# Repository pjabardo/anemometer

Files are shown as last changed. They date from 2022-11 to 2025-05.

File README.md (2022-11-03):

# envconds
Temperature, Pressure and Humidity measurement board and software

The objective of this project is to develop a board that reads environmental conditions including
 * Temperature using DS18B20 sensor
 * Pressure using the BMP280 sensor
 * Humidity using the DHT22 sensor

In the future, more sensors could be added.

The board uses a ESP32 microcontroller, in particular the Devkit v1 board with 30 pins. Embeded programming is done using arduino framework.

The folder `kicad` contains the schematics of the board.

For now a simple communication protocol over the serial line is used. In the future MQTT should be used.

To read a value, user should send the command `*XY` where `X` refers to the sensor and `Y` the variable being read. The following variables can be read:

 * `HH` - Humidity from the DHT22
 * `HT` - Temperature from the DHT22
 * `PP` - Atmospheric pressure from the BMP280
 * `PT` - Temperature from the BMP280
 * `Tx' - where x is the temperature sensor.

 To read the atmospheric pressure, the command `*PP` should be sent to the microcontroller. The response is sent as a line of text containing the value as an ASCII string.

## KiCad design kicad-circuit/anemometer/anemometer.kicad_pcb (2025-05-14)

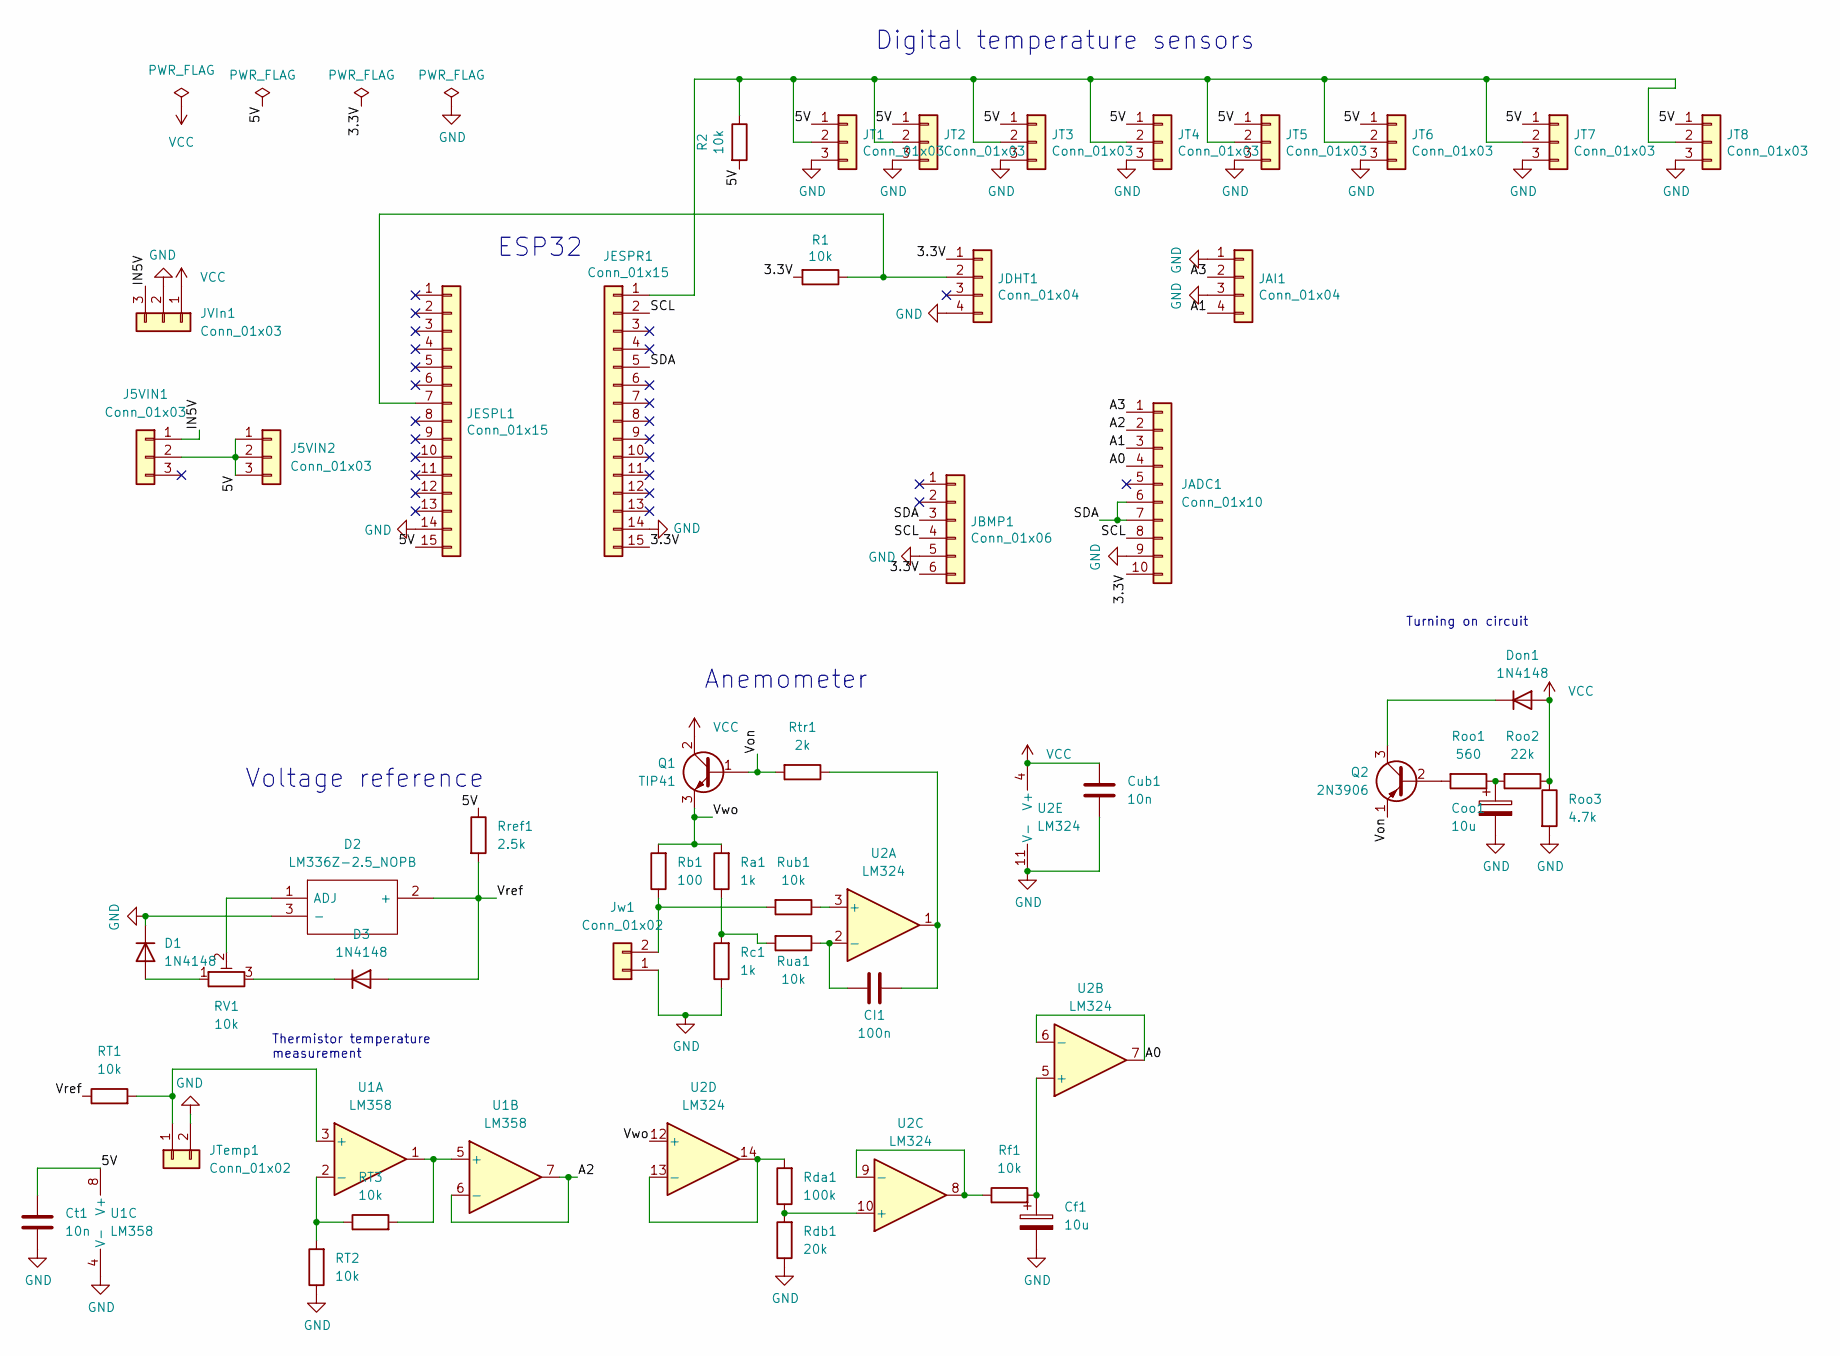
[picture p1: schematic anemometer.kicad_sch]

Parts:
CI1: 100n; C_Rect_L7.2mm_W3.5mm_P5.00mm_FKS2_FKP2_MKS2_MKP2
Cf1: 10u; CP_Radial_D5.0mm_P2.50mm
Coo1: 10u; CP_Radial_D5.0mm_P2.50mm
Ct1: 10n; C_Disc_D5.0mm_W2.5mm_P2.50mm
Cub1: 10n; C_Disc_D5.0mm_W2.5mm_P2.50mm
D1, D3: 1N4148; D_DO-35_SOD27_P7.62mm_Horizontal
D2: LM336Z-2.5_NOPB; TO-92_Inline_Wide; Manufacturer_Part_Number LM336Z-2.5/NOPB; Mouser Part Number 926-LM336Z-2.5/NOPB
Don1: 1N4148; D_DO-35_SOD27_P7.62mm_Horizontal
J5VIN1, J5VIN2: Conn_01x03; PinSocket_1x03_P2.54mm_Vertical
JADC1: Conn_01x10; PinSocket_1x10_P2.54mm_Vertical
JAI1: Conn_01x04; TerminalBlock_bornier-4_P5.08mm
JBMP1: Conn_01x06; PinSocket_1x06_P2.54mm_Vertical
JDHT1: Conn_01x04; PinSocket_1x04_P2.54mm_Vertical
JESPL1: Conn_01x15; PinSocket_1x15_P2.54mm_Vertical
JESPR1: Conn_01x15; PinSocket_1x15_P2.54mm_Vertical
JT1, JT2, JT3, JT4, JT5, JT6, JT7, JT8: Conn_01x03; PinHeader_1x03_P2.54mm_Vertical
JTemp1: Conn_01x02; TerminalBlock_bornier-2_P5.08mm
JVIn1: Conn_01x03; TerminalBlock_bornier-3_P5.08mm
Jw1: Conn_01x02; TerminalBlock_bornier-2_P5.08mm
Q1: TIP41; TO-220-3_Horizontal_TabUp
Q2: 2N3906; TO-92_Inline_Wide
R1, R2: 10k; R_Axial_DIN0207_L6.3mm_D2.5mm_P10.16mm_Horizontal
RT1, RT2, RT3: 10k; R_Axial_DIN0207_L6.3mm_D2.5mm_P10.16mm_Horizontal
RV1: 10k; Potentiometer_Bourns_3296W_Vertical
Ra1: 1k; R_Axial_DIN0207_L6.3mm_D2.5mm_P10.16mm_Horizontal
Rb1: 100; R_Axial_DIN0414_L11.9mm_D4.5mm_P15.24mm_Horizontal
Rc1: 1k; R_Axial_DIN0207_L6.3mm_D2.5mm_P10.16mm_Horizontal
Rda1: 100k; R_Axial_DIN0207_L6.3mm_D2.5mm_P10.16mm_Horizontal
Rdb1: 20k; R_Axial_DIN0207_L6.3mm_D2.5mm_P10.16mm_Horizontal
Rf1: 10k; R_Axial_DIN0207_L6.3mm_D2.5mm_P10.16mm_Horizontal
Roo1: 560; R_Axial_DIN0207_L6.3mm_D2.5mm_P10.16mm_Horizontal
Roo2: 22k; R_Axial_DIN0207_L6.3mm_D2.5mm_P10.16mm_Horizontal
Roo3: 4.7k; R_Axial_DIN0207_L6.3mm_D2.5mm_P10.16mm_Horizontal
Rref1: 2.5k; R_Axial_DIN0207_L6.3mm_D2.5mm_P10.16mm_Horizontal
Rtr1: 2k; R_Axial_DIN0207_L6.3mm_D2.5mm_P10.16mm_Horizontal
Rua1: 10k; R_Axial_DIN0207_L6.3mm_D2.5mm_P10.16mm_Horizontal
Rub1: 10k; R_Axial_DIN0207_L6.3mm_D2.5mm_P10.16mm_Horizontal
U1: LM358; DIP-8_W7.62mm_LongPads
U2: LM324; DIP-14_W7.62mm_Socket_LongPads

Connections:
/3.3V: JADC1.10, JBMP1.6, JDHT1.1, JESPR1.15, R1.2
/5V: Ct1.1, J5VIN1.2, J5VIN2.1, J5VIN2.2, J5VIN2.3, JESPL1.15, JT1.1, JT2.1, JT3.1, JT4.1, JT5.1, JT6.1, JT7.1, JT8.1, R2.2, Rref1.1, U1.8 (V+)
/A0: JADC1.4, U2.6 (-), U2.7
/A1: JADC1.3, JAI1.4
/A2: JADC1.2, U1.6 (-), U1.7
/A3: JADC1.1, JAI1.2
/IN5V: J5VIN1.1, JVIn1.3
/SCL: JADC1.8, JBMP1.4, JESPR1.2
/SDA: JADC1.6, JADC1.7, JBMP1.3, JESPR1.5
/Von: Q1.1 (B), Q2.1 (E), Rtr1.2
/Vref: D2.2 (+), D3.2 (A), RT1.1, Rref1.2
/Vwo: Q1.3 (E), Ra1.2, Rb1.2, U2.12 (+)
GND: Cf1.2, Coo1.2, Ct1.2, Cub1.2, D1.1 (K), D2.3 (-), JADC1.9, JAI1.1, JAI1.3, JBMP1.5, JDHT1.4, JESPL1.14, JESPR1.14, JT1.3, JT2.3, JT3.3, JT4.3, JT5.3, JT6.3, JT7.3, JT8.3, JTemp1.2, JVIn1.2, Jw1.1, RT2.1, Rc1.1, Rdb1.1, Roo3.2, U1.4 (V-), U2.11 (V-)
unnamed: CI1.1, Rua1.1, U2.2 (-)
unnamed: CI1.2, Rtr1.1, U2.1
unnamed: Cf1.1, Rf1.2, U2.5 (+)
unnamed: Coo1.1, Roo1.1, Roo2.2
unnamed: D1.2 (A), RV1.1
unnamed: D2.1 (ADJ), RV1.2
unnamed: D3.1 (K), RV1.3
unnamed: Don1.1 (K), Q2.3 (C)
unnamed: JDHT1.2, JESPL1.7, R1.1
unnamed: JESPR1.1, JT1.2, JT2.2, JT3.2, JT4.2, JT5.2, JT6.2, JT7.2, JT8.2, R2.1
unnamed: JTemp1.1, RT1.2, U1.3 (+)
unnamed: Jw1.2, Rb1.1, Rub1.2
unnamed: Q2.2 (B), Roo1.2
unnamed: RT2.2, RT3.1, U1.2 (-)
unnamed: RT3.2, U1.1, U1.5 (+)
unnamed: Ra1.1, Rc1.2, Rua1.2
unnamed: Rda1.1, Rdb1.2, U2.10 (+)
unnamed: Rda1.2, U2.13 (-), U2.14
unnamed: Rf1.1, U2.8, U2.9 (-)
unnamed: Rub1.1, U2.3 (+)
VCC: Cub1.1, Don1.2 (A), JVIn1.1, Q1.2 (C), Roo2.1, Roo3.1, U2.4 (V+)

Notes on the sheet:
ESP32
Thermistor temperature measurement
Digital temperature sensors
Turning on circuit
Anemometer
Voltage reference

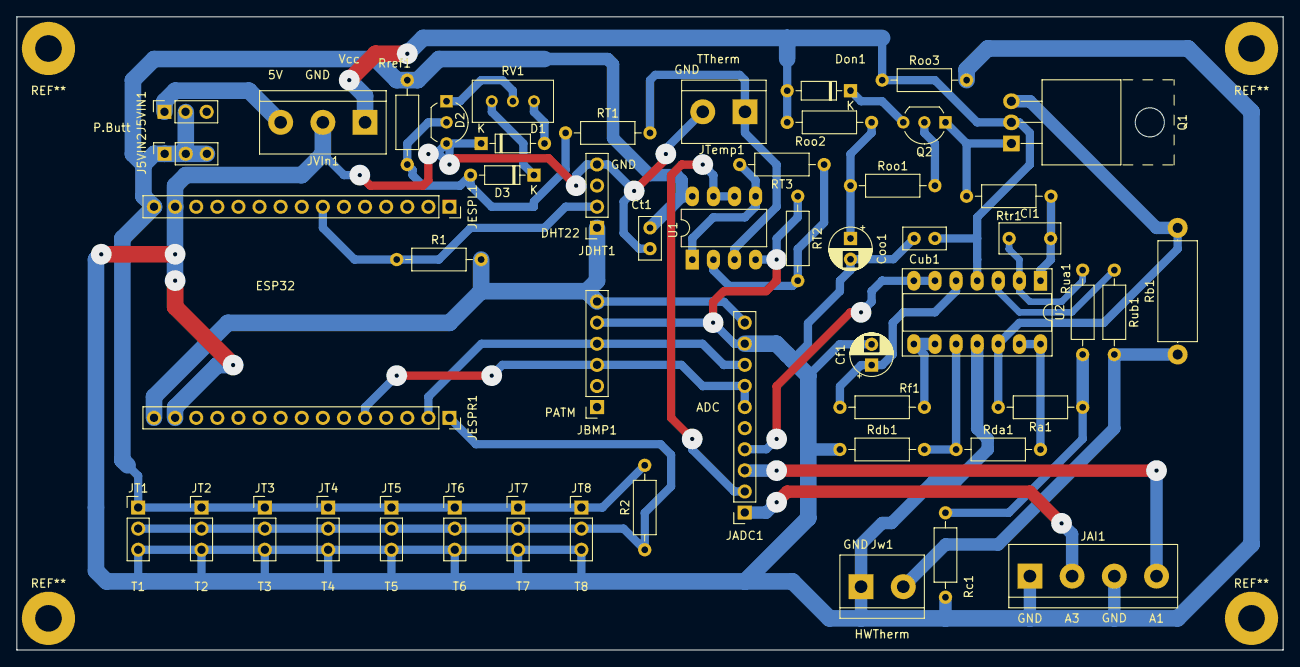
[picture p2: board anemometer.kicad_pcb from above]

Board: 2 copper layers, 152.4 x 76.2 mm, 51 parts (0 on the bottom side), 34 nets.

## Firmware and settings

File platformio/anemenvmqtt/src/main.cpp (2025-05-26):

#include<WiFi.h>

#include "mqtt_anem.h"


Anemometer anem;

const char *ssid = "rede-wifi";
const char *password = "senhadarede";
const char *mqtt_server = "192.168.0.180";
const uint16_t mqtt_port = 1883;

const char *mqtt_user = "usuariomqtt";
const char *mqtt_password = "senhamqtt";

WiFiClient esp_client;
PubSubClient client(esp_client);
const char *bname = "env";
MQTTAnem mqtt_anem(bname, &anem, &client);

void reconnect() {
  // Loop until we're reconnected
  while (!client.connected()) {
    Serial.print("Tentando conectar com o Broker do MQTT ...");
    // Attempt to connect
    if (client.connect("JAnem", mqtt_user, mqtt_password)) {
      Serial.println("conectado");
      mqtt_anem.publish_params();
    } else {
      Serial.print("failed, rc=");
      Serial.print(client.state());
      Serial.println(" try again in 5 seconds");
      // Wait 5 seconds before retrying
      delay(5000);
    }
  }
}


void setup(){
  Serial.begin(9600);
  
  WiFi.begin(ssid, password);
  
  Serial.println("\nConnecting");
  while (WiFi.status() != WL_CONNECTED){
    Serial.print(".");
    delay(200);
  }  
  Serial.println("\nConnected to the WiFi network!");

  Serial.print("\nLocal ESP32 IP: ");
  Serial.println(WiFi.localIP());

  client.setServer(mqtt_server, mqtt_port);
  
  
  anem.setup_anemometer();
  anem.setup_temperature();

  reconnect();
  

}



void loop(){

  if (!client.connected()) {
    reconnect();
    Serial.println(WiFi.localIP());
  }

  mqtt_anem.loop();


}

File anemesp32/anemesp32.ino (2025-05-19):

#include "anemometer.h"

Anemometer anem;
#define _USE_SERIAL_
//#define _USE_WIFI_

//#define _USE_BLUETOOTH_

#ifdef _USE_SERIAL_
#undef _USE_WIFIL_
#undef _USE_BLUETOOTH_



AnemometerComm<HardwareSerial> comm(&Serial, &anem);

void setup(){
  pinMode(ONBOARD_LED,OUTPUT);
  Serial.begin(115200);
  anem.setup_anemometer();
  
}



void loop(){
  digitalWrite(ONBOARD_LED, LOW);
  if (comm.available()){
    comm.repl();
  }
}

#endif //_USE_SERIAL_


#ifdef _USE_WIFI_
#undef _USE_SERIAL_
#undef _USE_BLUETOOTH_
//#define _ANEM_AP_ // ESP32 as accesspoint

#include<WiFi.h>
//const char *ssid = "pjsjanem";
//const char *password = "12345678";

const char *ssid = "tunel";
const char *password = "gvento123";

WiFiServer server(9525);

AnemometerComm<WiFiClient> comm(0, &anem);

void setup(){
  Serial.begin(115200);
  
#ifndef _ANEM_AP_
  WiFi.begin(ssid, password);
  Serial.println("\nConnecting");
  while (WiFi.status() != WL_CONNECTED){
    Serial.print(".");
    delay(200);
  }
  Serial.println("\nConnected to the WiFi networkd");
  Serial.print("\nLocal ESP32 IP: ");
  Serial.println(WiFi.localIP());
#else  // _ANEM_AP_
  Serial.println("Setting access point...");
  WiFi.softAP(ssid, password);
  Serial.print("Access point IP: ");
  Serial.println(WiFi.softAPIP());
#endif // _ANEM_AP_

  server.begin();
  
  anem.setup_anemometer();
}



void loop(){
  WiFiClient client = server.available();
  delay(500);


  if (client){
    client.setTimeout(1);
    Serial.println("Client connected!");
    while (client.connected()){
      comm.set_comm(&client);

      if (comm.available()){
        comm.repl();
      }
    }
  }
  //Serial.println("Finished loop!");
}



#endif

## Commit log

2022-11-03 Adding KiCAD files to the repository
    I believe the circuit is correct. I will need to check the circuit thoroughly and then build the board.
    [anemometer.kicad_pcb, anemometer.kicad_sch, anemometer.sch]
2022-11-04 Changed a little bit the tracks on the upper side
    Since I will be building the boards by hand, the upper side tracks should no pass under resistors and other components so I rearranged a few things.
    [anemometer.kicad_pcb]
2022-11-14 Implemented basic arduino code and python code
    It appears to be working. But I still need improve the software, basically a need to implement some sort of streaming from the analog to digital converter.
    I found an error on the board: the temperature circuit was wrong. I corrected it on the physical board I built but I still need to correct the Kicad project.
    Another thing that I should improve is the disposition of the digital temperature sensors. If I just switch pins I could solder a digital sensor directly on the board. May be I will doit later...
    [anemesp32.ino, anemesp32.py]
2022-11-17 Corrected the thermistor temperature circuit.
    There was a mistake. I corrected it ion the board that I built and now it is corrected in the Kicad circuit.
    [anemometer.kicad_pcb, anemometer.kicad_sch]
2022-11-17 Switched pins of DS18B20 temp. sensor
    Now the tracks are positioned in the same orientation as the pins in the TO-92 packaging. Not important but now I can solder one sensor directly on the board.
    [anemometer.kicad_pcb, anemometer.kicad_sch]
2022-11-18 Moved some components so that the TIP41 transistor can lay on its back
    [anemometer.kicad_pcb, anemometer.kicad_sch]
2023-02-01 Working on the software
    Not working yet. Just testing stuff
    [anemesp32.ino, anemometer.h]
2023-03-20 Working on wifi
    COuldn't do anything besides connecting to the wifi router.
    Still figuring things out. This code is crap, just for experimenting.
    [anemometer-B_Cu.gbl, anemometer-B_Mask.gbs, anemometer-B_Paste.gbp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]
2023-10-03 Improved the software *a lot*
    Now we can choose which AI channels should be read and we can stop data acquisition in the middle of a scan!
    We can also set the temperature resolution but I couldn't notice any difference in speed. I will have to study this more.
    What I need to do now is improve flexibility in using the DS18b20 temperature sensors.
2023-10-05 Improving the reliability of the the code
    I have been experiencing problems with the power supply I believe. Nothing to do with this but still...
    [anemesp32.ino, anemometer.h]
2023-10-17 Now the ESP32 can be used as an access point
    Just define the _ANEM_AP_
2023-10-20 Commented out the code to set the esp32 as an access point
2025-05-14 Circuit looks like it is working on KiCAD 9
    [anemometer.kicad_pcb, anemometer.kicad_sch]
2025-05-18 Working on it. Some serious bug. Nothing is working
    I will have to figure out what is going on.
    [anemometer.h, main.cpp]
2025-05-19 Full interface appears to be working
    Now we can add or remove stuff that should be acquired and published in the MQTT broker. I need to setup better defaults and test the interface.
    [anemesp32.ino, anemometer.h, main.cpp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]
2025-05-22 Added a unit field to each measurement and AI output is now voltage.
    The code compiles but I still need test it with the board operating.
2025-05-23 Setting up defaults
    The temperature of the BMP280 is not read by default. The board inside the box warms up and the temperature is not very accurate.
    I have also disabled the analog input. There are several issues with the anemometer circuit. But the board is good enough for environment measurements.
    [main.cpp, mqtt_anem.cpp]
2025-05-26 Setting up retained params is called in reconnect
    Now if the broker goes down, when reconnecting, the retained topics will be published again.
    [main.cpp]
2025-05-28 Calibration correction for atmospheric pressure
    Also prepared for calibration of temperature sensors (DS18B20).
    I should think about a generic interface for calibration curves and units.
    [anemometer.h, mqtt_anem.cpp]
2025-07-24 Corrected bug when reading DS18B20 temperature sensors
    Only the first detected was being read.
    [mqtt_anem.cpp]
